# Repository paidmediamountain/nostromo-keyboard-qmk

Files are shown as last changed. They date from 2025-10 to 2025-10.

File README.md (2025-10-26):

# Weyland-Yutani Nostromo Custom Keyboard

A custom 45-key mechanical keyboard with QMK firmware, inspired by the iconic spacecraft from the Alien franchise.

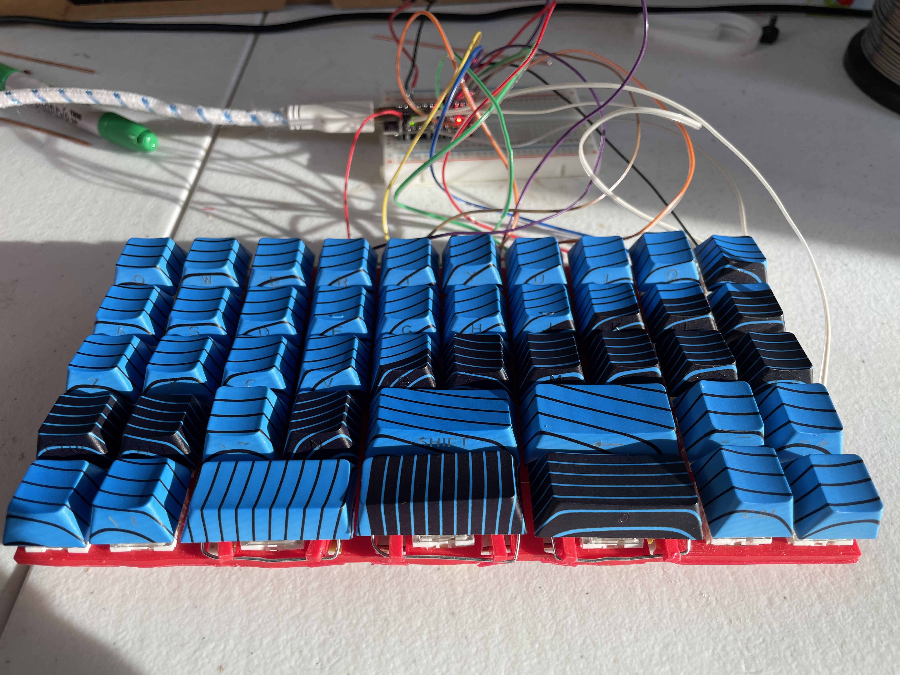
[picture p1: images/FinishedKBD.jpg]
Finished Keyboard


## Features

- **45-key layout** with 2u stabilized keys for Tab, Backspace, Shift, Space, and Return
- **3 layers** accessible via dual function keys
- **Pro Micro** based (ATmega32U4)
- **QMK firmware** with full customization support
- **Handwired** construction with 1N4148 diodes

## Layout

### Base Layer (Layer 0)
```
┌───┬───┬───┬───┬───┬───┬───┬───┬───┬───┐
│ Q │ W │ E │ R │ T │ Y │ U │ I │ O │ P │
├───┼───┼───┼───┼───┼───┼───┼───┼───┼───┤
│ A │ S │ D │ F │ G │ H │ J │ K │ L │ ; │
├───┼───┼───┼───┼───┼───┼───┼───┼───┼───┤
│ Z │ X │ C │ V │ B │ N │ M │ , │ . │ / │
├───┼───┼───┼───┼───────┼───────┼───┼───┤
│Ctl│Alt│ ` │ \ │Tab 2u │Bksp2u │ ' │ = │
├───┼───┼───────┼───────┼───────┼───┼───┤
│Fn1│Sys│Shift2u│Space2u│Return2│Fn2│Esc│
└───┴───┴───────┴───────┴───────┴───┴───┘
```

### Layer 1: Numbers & Navigation (Hold LEFT Fn1)
```
┌───┬───┬───┬───┬───┬───┬───┬───┬───┬───┐
│ 1 │ 2 │ 3 │ 4 │ 5 │ 6 │ 7 │ 8 │ 9 │ 0 │
├───┼───┼───┼───┼───┼───┼───┼───┼───┼───┤
│   │   │   │   │   │ ← │ ↓ │ ↑ │ → │Del│
├───┼───┼───┼───┼───┼───┼───┼───┼───┼───┤
│   │   │   │   │   │Hom│PgD│PgU│End│Ins│
├───┼───┼───┼───┼───────┼───────┼───┼───┤
│   │   │   │   │       │  Del  │ [ │ ] │
├───┼───┼───────┼───────┼───────┼───┼───┤
│Fn1│   │       │       │       │   │   │
└───┴───┴───────┴───────┴───────┴───┴───┘
```

Features:
- **Numbers:** Top row becomes 1-0
- **Arrow keys:** HJKL (vim-style: H=←, J=↓, K=↑, L=→)
- **Navigation:** Home, End, Page Up, Page Down
- **Extras:** Delete, Insert, Brackets [ ]

### Layer 2: Function Keys & Media (Hold RIGHT Fn2)
```
┌───┬───┬───┬───┬───┬───┬───┬───┬───┬───┐
│F1 │F2 │F3 │F4 │F5 │F6 │F7 │F8 │F9 │F10│
├───┼───┼───┼───┼───┼───┼───┼───┼───┼───┤
│F11│F12│   │   │   │Prv│VoD│VoU│Nxt│Mut│
├───┼───┼───┼───┼───┼───┼───┼───┼───┼───┤
│   │   │   │   │   │Stp│Ply│Pau│   │   │
├───┼───┼───┼───┼───────┼───────┼───┼───┤
│   │   │   │   │       │       │ - │ + │
├───┼───┼───────┼───────┼───────┼───┼───┤
│   │   │       │       │       │Fn2│Rst│
└───┴───┴───────┴───────┴───────┴───┴───┘
```

Features:
- **Function keys:** F1-F12
- **Media controls:** Play/Pause, Next, Previous, Stop
- **Volume:** Volume Up/Down, Mute
- **Special:** QK_BOOT (Rst) for firmware flashing

## Hardware

### 3D Printable Files
- **Plate STL**: `hardware/plate.stl` - Mounting plate for switches

### Required Components
- 1x Pro Micro (or compatible ATmega32U4 board)
- 45x Cherry MX compatible switches
- 45x 1N4148 diodes
- Wire for matrix
- USB cable
- Case/mounting solution (or 3D print the included plate)

### Matrix Layout (5x10)
```
        Col0  Col1  Col2  Col3  Col4  Col5  Col6  Col7  Col8  Col9
Row0    Q     W     E     R     T     Y     U     I     O     P
Row1    A     S     D     F     G     H     J     K     L     ;
Row2    Z     X     C     V     B     N     M     ,     .     /
Row3    Ctrl  Alt   `     \     Tab   -     Bksp  -     '     =
Row4    Fn1   -     Shift -     Space -     Enter -     Fn2   Esc
```
Note: Dashes (-) indicate positions that are part of 2u keys but have no switch.

### Pro Micro Pinout
```
         Pro Micro
     ┌─────────────┐
TX0  │ D3       RAW│
RX1  │ D2       GND│
GND  │ GND      RST│
GND  │ GND      VCC│
2    │ D1       F4 │ A3
3    │ D0       F5 │ A2
4    │ D4       F6 │ A1
5    │ C6       F7 │ A0
6    │ D7       B1 │ 15
7    │ E6       B3 │ 14
8    │ B4       B2 │ 16
9    │ B5       B6 │ 10
     └─────────────┘
```

### Pin Configuration

#### Matrix Rows (5 total)
- Row 0 → TX0 (D3) - Top row (Q through P)
- Row 1 → RX1 (D2) - Second row (A through ;)
- Row 2 → Pin 2 (D1) - Third row (Z through /)
- Row 3 → Pin 3 (D0) - Fourth row (Ctrl through =)
- Row 4 → Pin 4 (D4) - Bottom row (Fn1 through Esc)

#### Matrix Columns (10 total)
- Col 0 → Pin 5 (C6)
- Col 1 → Pin 6 (D7)
- Col 2 → Pin 7 (E6)
- Col 3 → Pin 8 (B4)
- Col 4 → Pin 9 (B5)
- Col 5 → Pin 10 (B6)
- Col 6 → Pin 16 (B2)
- Col 7 → Pin 14 (B3)
- Col 8 → Pin 15 (B1)
- Col 9 → Pin A0 (F7)

### Wiring Notes
- Diode direction: COL2ROW (diode stripe towards row)
- One diode per switch (45 total)
- 2u keys use stabilizers but single switch in center position
- Debounce set to 10ms for stability

#### Diode Connection
```
Switch Pin 1 ───┤>├─── To Row Wire
                Diode
                (stripe towards row)

Switch Pin 2 ────────── To Column Wire
```

## Build Gallery

### Pro Micro Controller
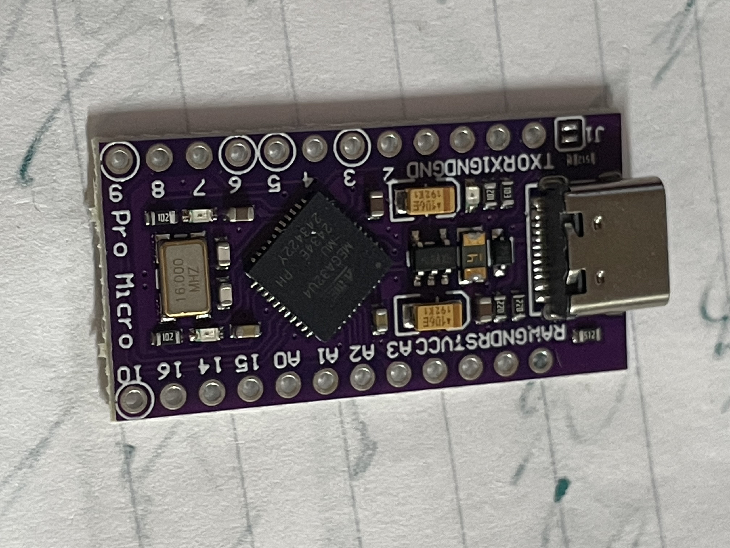
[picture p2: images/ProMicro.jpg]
Pro Micro


### Switch Installation
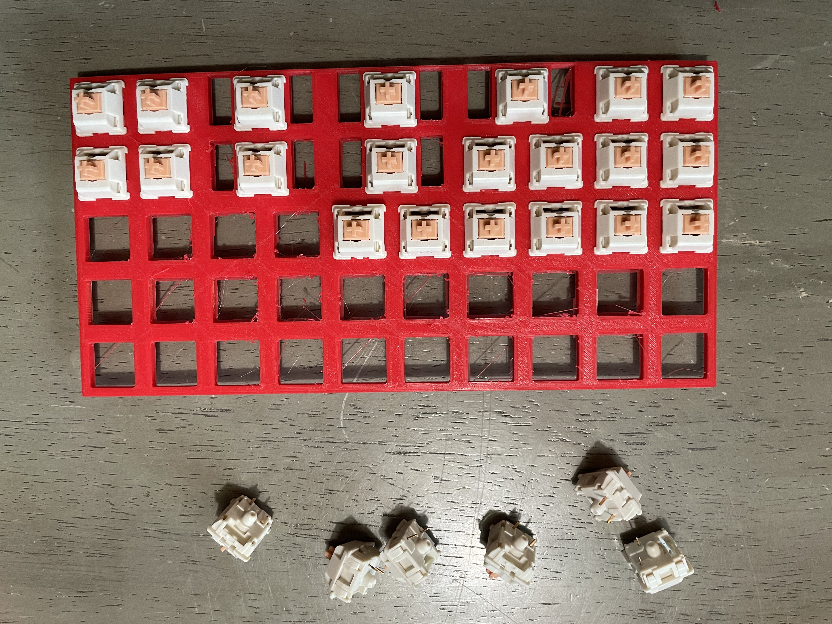
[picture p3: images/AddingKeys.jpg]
Adding Keys


### Matrix Wiring
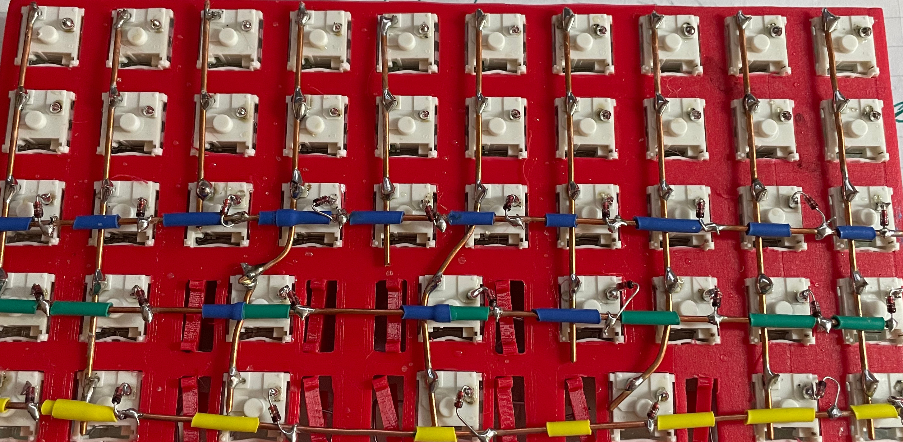
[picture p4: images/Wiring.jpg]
Wiring

*Note: Work in progress - top 2 rows not yet wired in this photo*

## Building the Firmware

### Prerequisites
# Install QMK
pip3 install qmk
qmk setup

### Method 1: Copy to QMK Directory
# Copy the firmware folder to your QMK installation
cp -r firmware/weyland_yutani ~/qmk_firmware/keyboards/

# Compile
cd ~/qmk_firmware
qmk compile -kb weyland_yutani/nostromo -km default

# Flash (reset Pro Micro when prompted)
qmk flash -kb weyland_yutani/nostromo -km default

### Method 2: Use Pre-compiled Hex
# Flash the pre-compiled firmware directly
avrdude -p atmega32u4 -c avr109 -P /dev/ttyACM0 -U flash:w:firmware/weyland_yutani_nostromo_default.hex:i

## Flashing Instructions

1. Run the flash command
2. When you see "Waiting for USB serial port - reset your controller now"
3. Quickly double-tap the reset button on your Pro Micro (or short RST to GND twice)
4. The bootloader window is only open for 8 seconds
5. If successful, you'll see the upload progress

### Troubleshooting Flash Issues
- Make sure you're in the `dialout` group: `sudo usermod -a -G dialout $USER`
- Try different USB cables and ports
- Reset timing is critical - practice the double-tap rhythm
- Use the included `flash_with_reset.sh` script for automated reset

## Customization

### Editing the Keymap
Edit `firmware/weyland_yutani/nostromo/keymaps/default/keymap.c` to customize your layout.

Common modifications:
- Change key assignments
- Add more layers
- Configure macros
- Adjust media keys

### Adding Features
The keyboard.json supports enabling:
- RGB lighting
- Backlight
- NKRO (N-Key Rollover)
- Additional QMK features

## Troubleshooting

### Key Not Working
1. Check solder connections on switch
2. Verify diode orientation (stripe towards row)
3. Test continuity with multimeter
4. Check wire connections to Pro Micro pins

### Inconsistent Key Response
1. Increase debounce time in keyboard.json
2. Check for cold solder joints
3. Clean switch contacts
4. Verify stable USB connection

### Cannot Enter Bootloader
1. Try shorting RST to GND directly
2. Hold reset while plugging in USB
3. Check Pro Micro board health
4. Verify USB cable is data-capable

## Project Structure
```
nostromo-keyboard-qmk/
├── firmware/               # QMK firmware files
│   └── weyland_yutani/
│       └── nostromo/
├── hardware/               # 3D printable files
│   └── plate.stl
├── docs/                   # Documentation
├── scripts/                # Helper scripts
├── images/                 # Photos and diagrams
└── README.md              # This file
```

## License

This project is open source and available under the MIT License.

## Credits

- Built with [QMK Firmware](https://qmk.fm/)
- Inspired by the main computer terminal used by the captain and Ripley aboard the Nostromo spacecraft from the Alien franchise
- Special thanks to the QMK community

**Note:** This is an unofficial fan project. "Alien," "Nostromo," "Ripley," and "Weyland-Yutani" are trademarks of 20th Century Studios.

## Contact

For questions, issues, or suggestions, please open an issue on GitHub.

---
*"Building the perfect keyboard, one key at a time"*

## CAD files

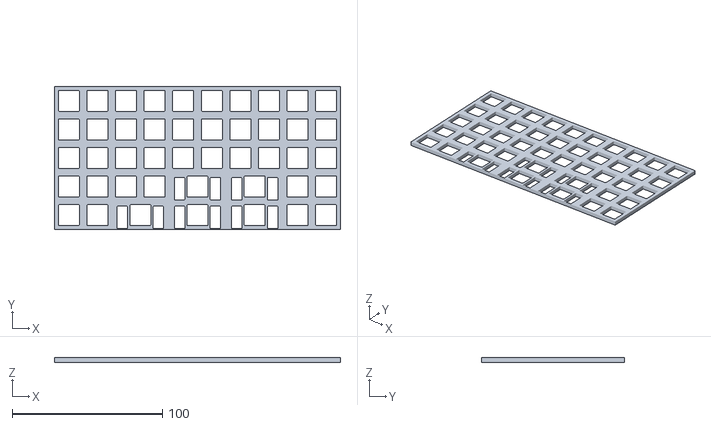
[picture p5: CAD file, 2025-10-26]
hardware/plate.stl
190.5 x 95.2 x 3.00

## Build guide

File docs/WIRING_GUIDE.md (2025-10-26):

# Nostromo Keyboard Wiring Guide

## Overview
This guide details the complete wiring for the Weyland-Yutani Nostromo keyboard using a Pro Micro controller.

## Matrix Layout (5x10)

### Physical Key Matrix
```
        Col0  Col1  Col2  Col3  Col4  Col5  Col6  Col7  Col8  Col9
Row0    Q     W     E     R     T     Y     U     I     O     P
Row1    A     S     D     F     G     H     J     K     L     ;
Row2    Z     X     C     V     B     N     M     ,     .     /
Row3    Ctrl  Alt   `     \     Tab   -     Bksp  -     '     =
Row4    Fn1   -     Shift -     Space -     Enter -     Fn2   Esc
```

Note: Dashes (-) indicate positions that are part of 2u keys but have no switch.

## Pro Micro Pin Assignments

### Left Side (when USB port is facing up)
```
         Pro Micro
     ┌─────────────┐
TX0  │ D3       RAW│
RX1  │ D2       GND│
GND  │ GND      RST│
GND  │ GND      VCC│
2    │ D1       F4 │ A3
3    │ D0       F5 │ A2
4    │ D4       F6 │ A1
5    │ C6       F7 │ A0
6    │ D7       B1 │ 15
7    │ E6       B3 │ 14
8    │ B4       B2 │ 16
9    │ B5       B6 │ 10
     └─────────────┘
```

### Pin to Matrix Connections

#### ROW Connections (5 wires)
- **Row 0** → TX0 (D3) - Top row (Q through P)
- **Row 1** → RX1 (D2) - Second row (A through ;)
- **Row 2** → Pin 2 (D1) - Third row (Z through /)
- **Row 3** → Pin 3 (D0) - Fourth row (Ctrl through =)
- **Row 4** → Pin 4 (D4) - Bottom row (Fn1 through Esc)

#### COLUMN Connections (10 wires)
- **Col 0** → Pin 5 (C6)
- **Col 1** → Pin 6 (D7)
- **Col 2** → Pin 7 (E6)
- **Col 3** → Pin 8 (B4)
- **Col 4** → Pin 9 (B5)
- **Col 5** → Pin 10 (B6)
- **Col 6** → Pin 16 (B2)
- **Col 7** → Pin 14 (B3)
- **Col 8** → Pin 15 (B1)
- **Col 9** → Pin A0 (F7)

## Diode Wiring

### Diode Orientation
- **Direction**: COL2ROW
- **Installation**: Diode cathode (stripe) connects to the ROW wire
- **One diode per switch** (45 total)

### Diode Connection Diagram
```
    Switch Pin 1 ───┤>├─── To Row Wire
                    Diode
                    (stripe towards row)
    
    Switch Pin 2 ────────── To Column Wire
```

## Wiring Steps

### Step 1: Prepare the Diodes
1. Bend each diode into shape
2. The stripe (cathode) will connect to the row wire
3. The other end (anode) connects to one switch pin

### Step 2: Wire the Rows
1. Start with Row 0 (top row)
2. Connect the cathode (stripe) end of 10 diodes to a common row wire
3. Connect this row wire to TX0 (D3) on the Pro Micro
4. Repeat for all 5 rows

### Step 3: Wire the Columns
1. Starting with Column 0 (leftmost)
2. Connect all switches in that column with a common wire
3. Connect to the switch pin that doesn't have a diode
4. Route this column wire to Pin 5 (C6) on the Pro Micro
5. Repeat for all 10 columns

### Step 4: Handle 2u Keys
For 2u keys (Tab, Backspace, Shift, Space, Return):
- Mount stabilizers
- Install switch in the center position
- Wire only the center switch position
- Leave adjacent matrix positions empty (no switch/diode)

## Testing

### Continuity Test
Before powering on:
1. Test each diode with multimeter in diode mode
2. Verify row connections from Pro Micro pin to diodes
3. Verify column connections from Pro Micro pin to switches
4. Check for shorts between adjacent rows/columns

### Matrix Test
After flashing firmware:
1. Open a text editor
2. Press each key systematically
3. Verify correct character appears
4. Test all layer functions (Fn keys)

## Common Issues and Solutions

### Key not working
- Check diode orientation (stripe to row)
- Resolder cold joints
- Verify continuity with multimeter

### Multiple keys activate
- Check for shorts between columns
- Check for shorts between rows
- Verify diode is not shorted

### Entire row/column not working
- Check Pro Micro pin connection
- Test continuity from Pro Micro to switches
- Verify pin isn't damaged on Pro Micro

### Ghost keys or chatter
- Check diode installation
- Increase debounce in firmware (currently 10ms)
- Clean flux residue from PCB

## Color Coding Suggestion
For easier troubleshooting:
- **Red wires**: Rows (5 wires)
- **Blue wires**: Columns (10 wires)  
- **Black wire**: Ground (if adding LEDs later)
- **Yellow wire**: VCC/5V (if adding LEDs later)

## Additional Notes

### Wire Gauge
- Recommended: 24-26 AWG solid core wire
- Solid core is easier to route and solder
- Stranded wire is more flexible but harder to work with

### Soldering Tips
- Use flux for cleaner joints
- Tin wires before soldering to switches
- Keep iron temperature around 350°C (660°F)
- Clean iron tip regularly

### Cable Management
- Route wires along edges when possible
- Use hot glue to secure wires in place
- Keep wires short but with slight slack for flex
- Avoid crossing row and column wires when possible

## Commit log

2025-10-26 Add note about wiring progress in build gallery
2025-10-26 Add 3D printable plate STL and update credits
    [plate.stl]
